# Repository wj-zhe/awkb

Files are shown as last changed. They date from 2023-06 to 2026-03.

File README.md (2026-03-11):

# AWKB - A Weird Keyboard

Nothing fancy, just another Seeed Studio Xiao RP2040 based 36key split keyboard with features like
Japanese Matrix, trackball (pmw3360 based sensor), rotary encoder, and etc.

hardware: https://github.com/wj-zhe/awkb/tree/main/hardware/rev2  
firmware: https://github.com/wj-zhe/awkb/tree/main/firmware/rev2

optical sensor: https://github.com/wj-zhe/optical-sensor

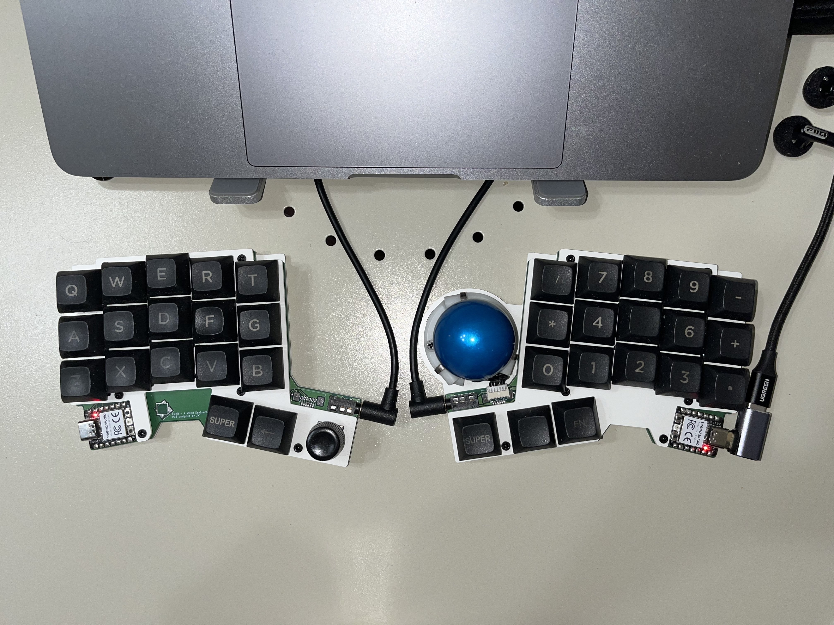
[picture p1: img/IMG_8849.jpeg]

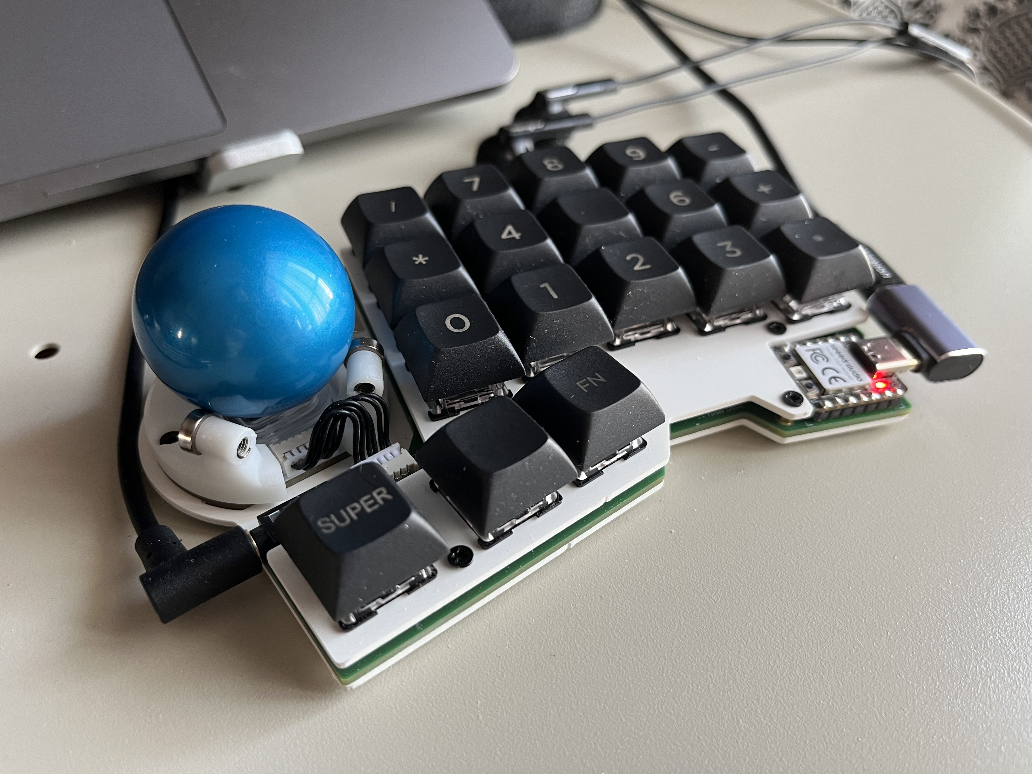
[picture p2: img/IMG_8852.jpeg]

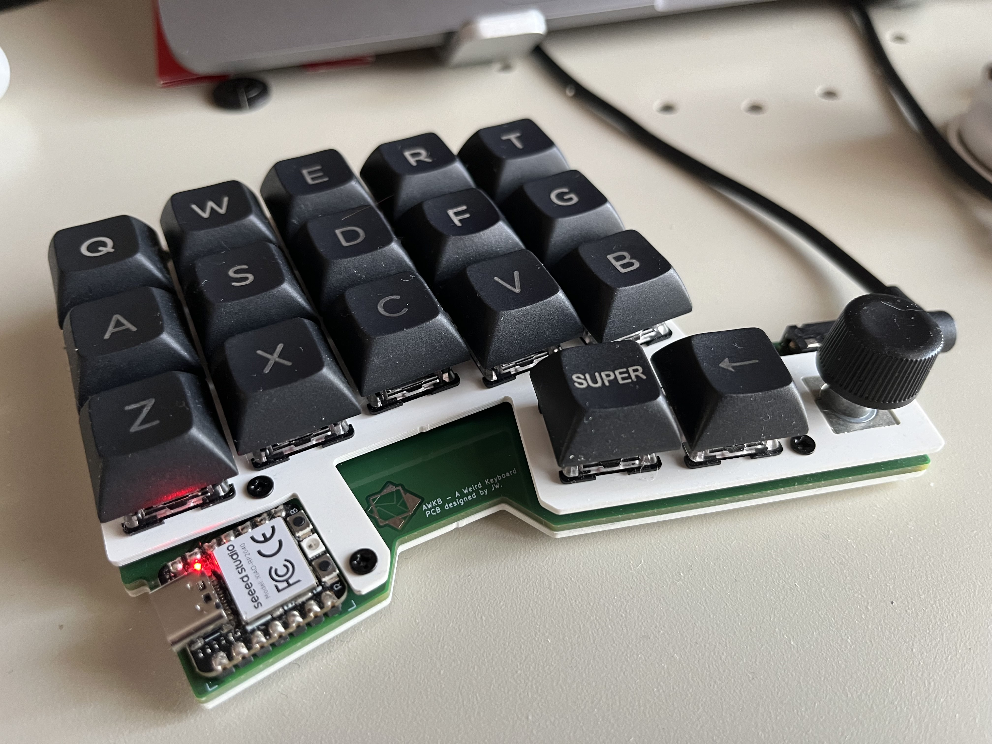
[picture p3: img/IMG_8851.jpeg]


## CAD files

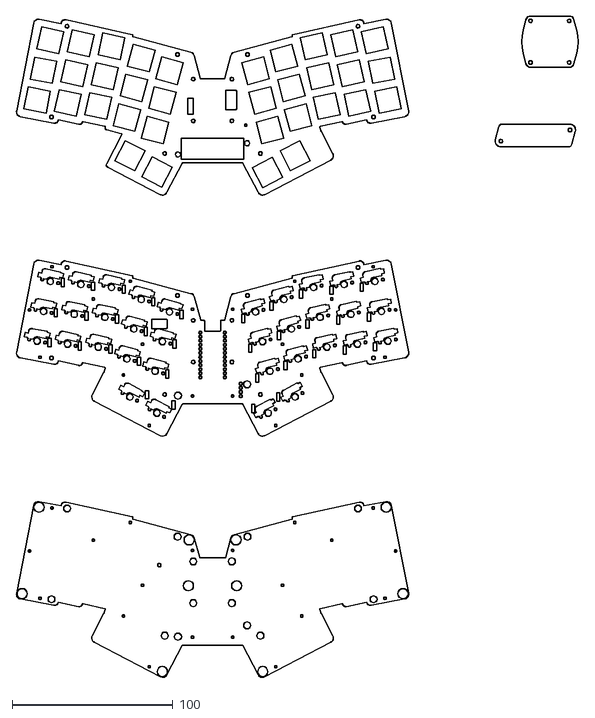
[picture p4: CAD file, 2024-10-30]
hardware/34/monosplit_rev1/case/cirque trackpad 23mm/all-plates-in-one.dxf
349.8 x 411.8

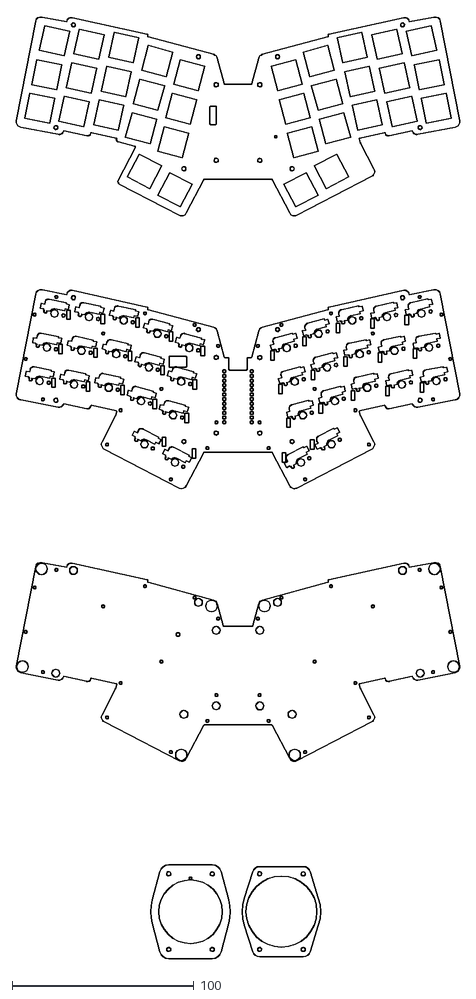
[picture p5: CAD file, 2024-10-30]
hardware/34/monosplit_rev1/case/cirque trackpad 35mm/all-in-one.dxf
244.1 x 518.1

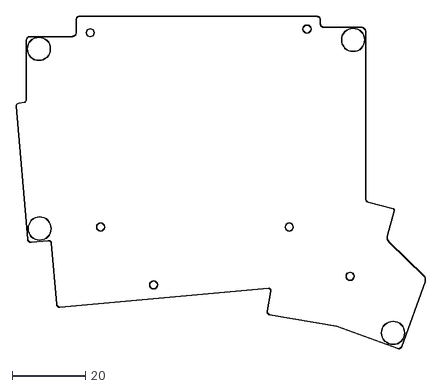
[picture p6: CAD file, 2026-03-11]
hardware/34/rev1/case-acrylic/dxf/AWKB-C-0-bottom-1mm-Edge_Cuts.dxf
111.5 x 90.6

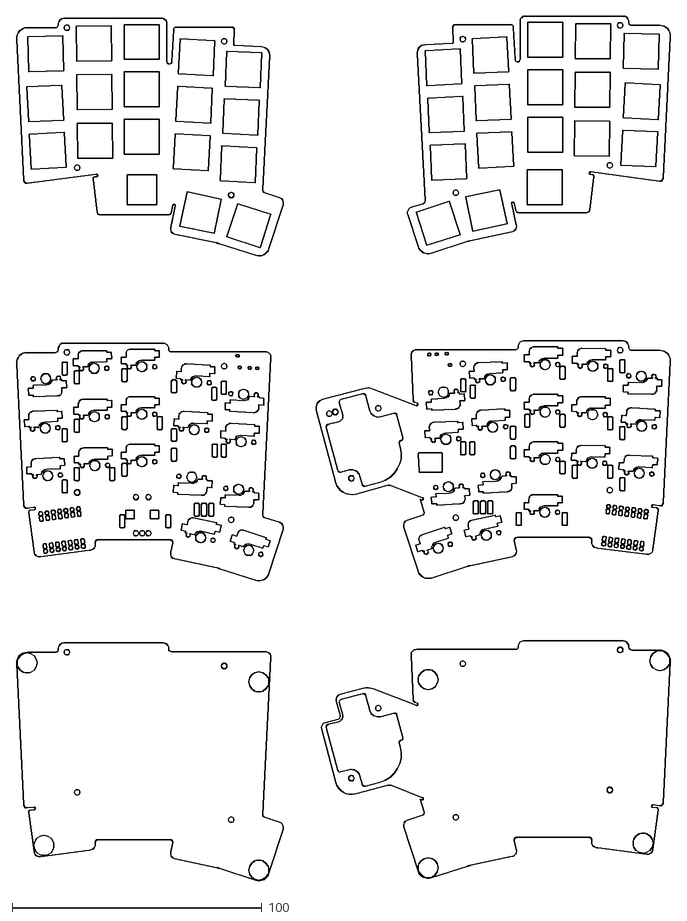
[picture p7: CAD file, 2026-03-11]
hardware/36/rev3/CASE/36_split_v3_stack_case-Edge_Cuts.dxf
261.8 x 346.2

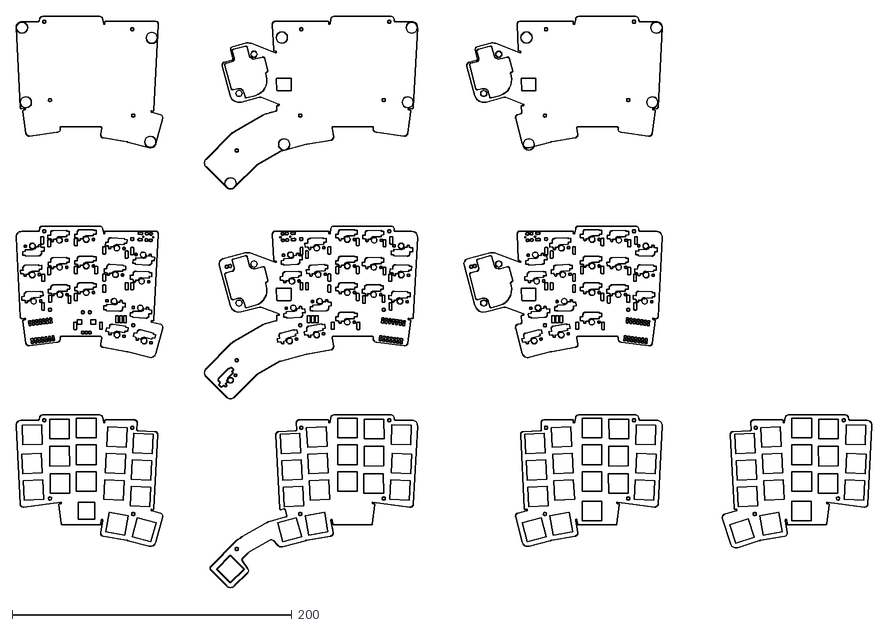
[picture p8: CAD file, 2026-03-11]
hardware/36/rev3/case_temp/gerber/36_split_v3_case-Edge_Cuts.dxf
612.3 x 408.5

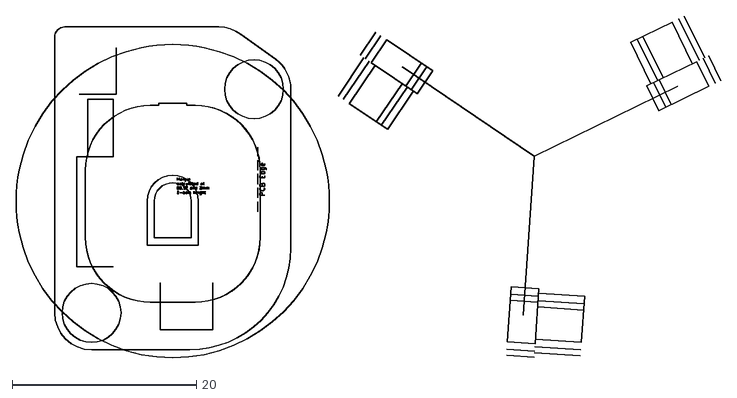
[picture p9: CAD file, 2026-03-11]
hardware/peripherals/pmw3360_fsr/pmw3360_fsr-User_Comments.dxf
76.5 x 37.1

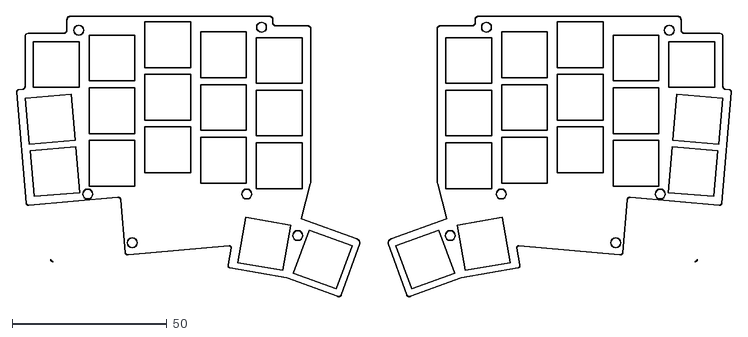
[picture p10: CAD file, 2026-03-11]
hardware/34/rev1/case-acrylic/dxf/AWKB-C-2-above PCB-1mm-Edge_Cuts.dxf
231.0 x 90.6

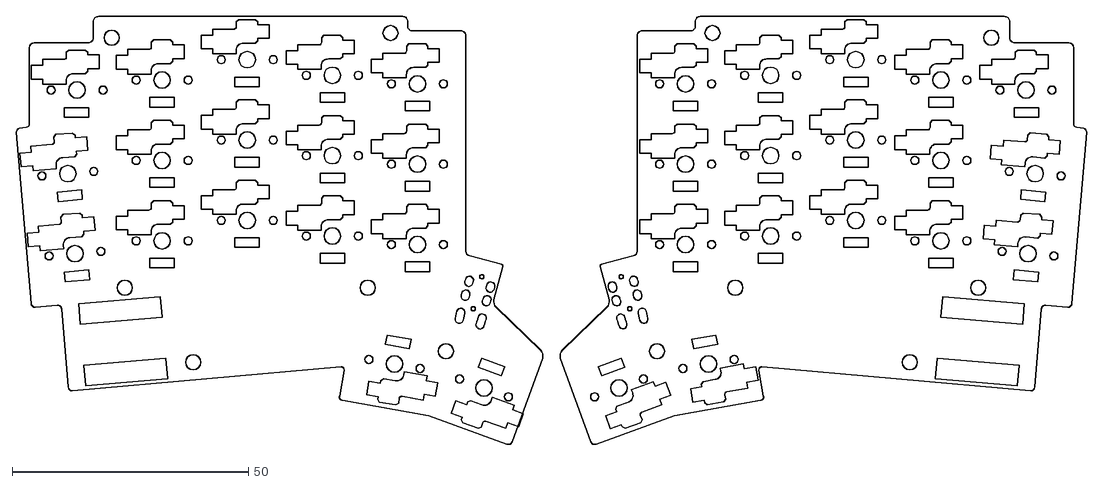
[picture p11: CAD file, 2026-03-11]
hardware/34/rev1/case-acrylic/dxf/AWKB-C-1-under PCB-2mm-Edge_Cuts.dxf
226.5 x 90.6

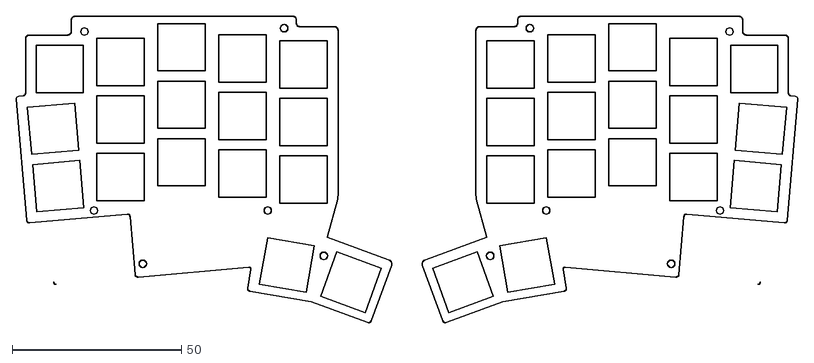
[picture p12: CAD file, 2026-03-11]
hardware/34/rev1/case-acrylic/dxf/AWKB-C-3-switch plate-1mm-Edge_Cuts.dxf
231.0 x 90.6

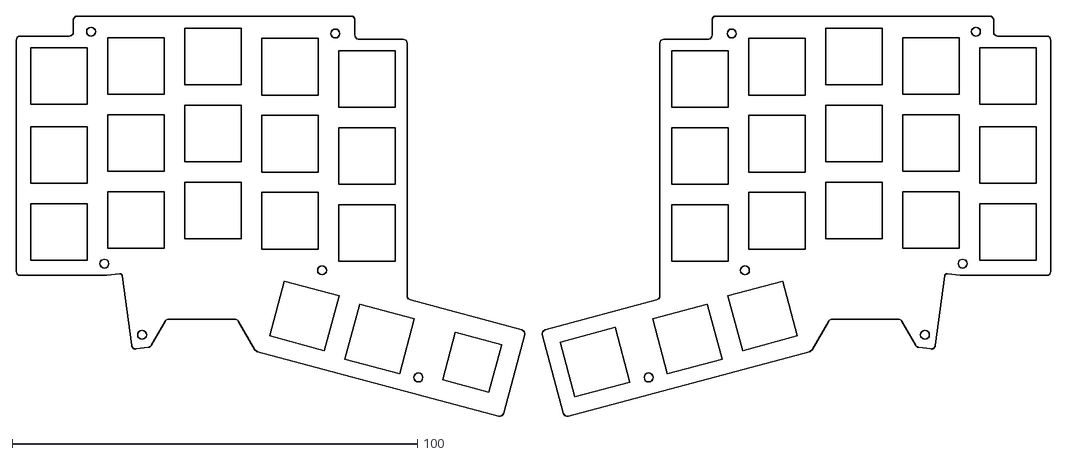
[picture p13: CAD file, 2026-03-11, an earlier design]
hardware/36/rev2/CASE/switch plate/awkb_v2_mx-switch_plate.dxf
255.2 x 98.9

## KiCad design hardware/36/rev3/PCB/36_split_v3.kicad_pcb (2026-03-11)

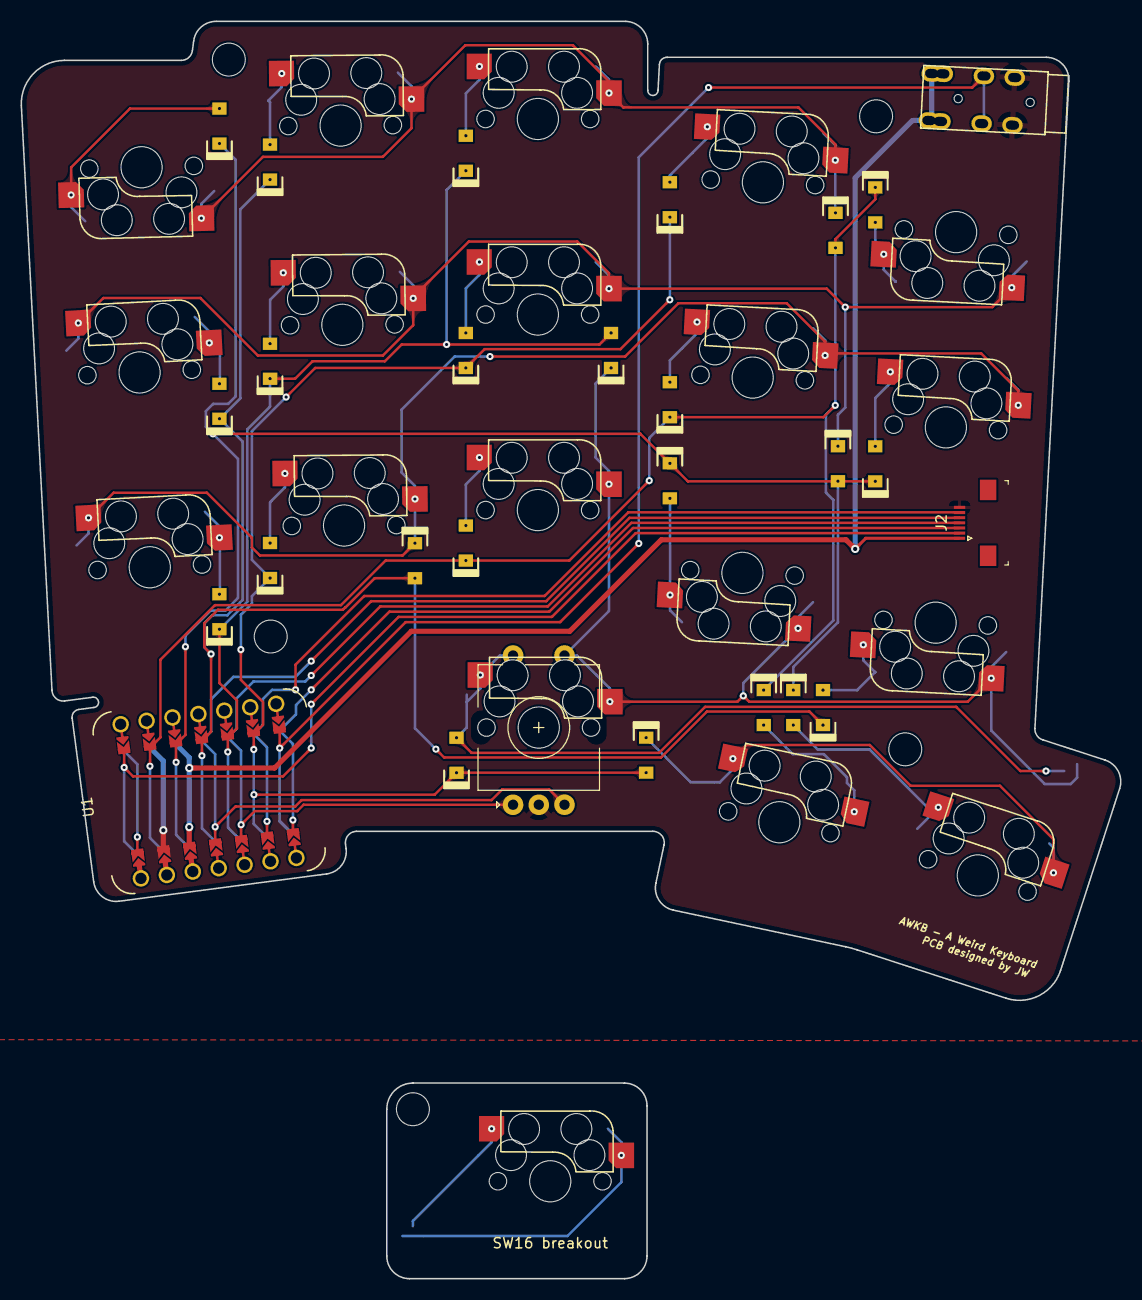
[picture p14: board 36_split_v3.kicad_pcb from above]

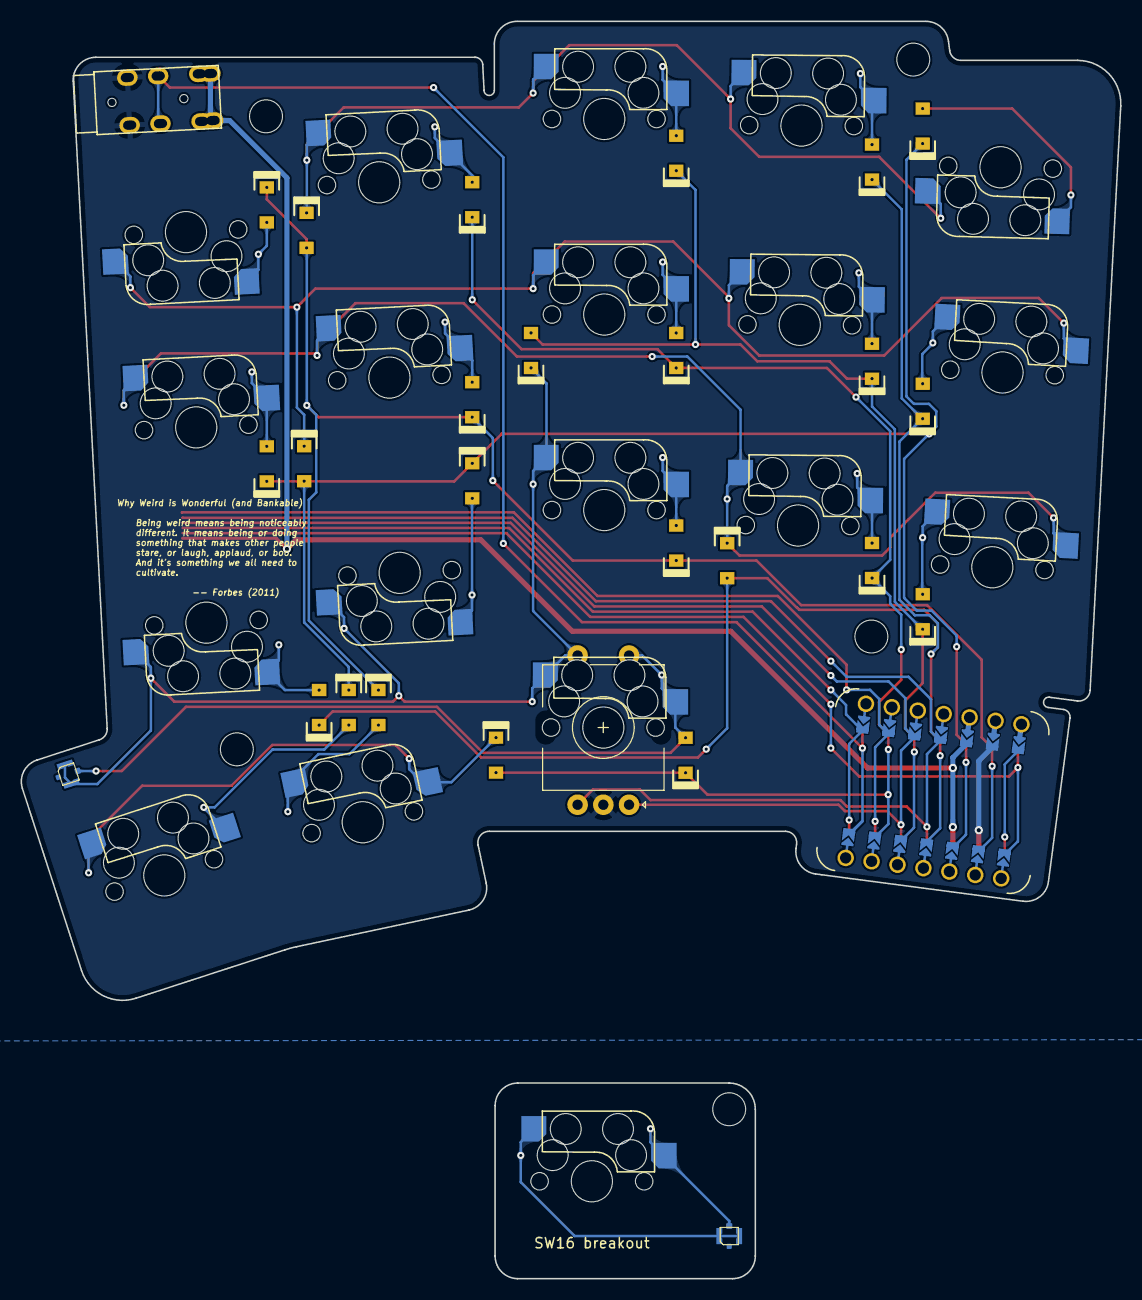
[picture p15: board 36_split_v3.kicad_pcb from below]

Board: 2 copper layers, 106.8 x 95.1 mm, 53 parts (3 on the bottom side), 38 nets.

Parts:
D1, D2, D3, D4, D5, D6, D7, D8, D9, D10, D11, D12, D13, D14, D15, D16, D17, D18: Diode; Diode_SOD123_THT_v3
D-1, D-2, D-3, D-4, D-5: Diode; Diode_SOD123_THT_v3
EC1: Rotary_Encoder_Switch; RotaryEncoder_Alps_EC11E-Switch_Vertical_H20mm_no_copper_MP
J1: 4PIN; TRRS-PJ-DPB2_mod
J2: Conn_01x07_Female; Conn_1x07-1MP_P0.5mm_Horizontal_Flip
J3, J4: Conn_Coaxial; Coaxial_MHF_2D_MHF_4_RECEPTACLE_20449_1C22_IPEX_4
SW1: SW1; CherryMX_Hotswap
SW2: SW2; CherryMX_Hotswap
SW3: SW3; CherryMX_Hotswap
SW4: SW4; CherryMX_Hotswap
SW5: SW5; CherryMX_Hotswap
SW6: SW6; CherryMX_Hotswap
SW7: SW7; CherryMX_Hotswap
SW8: SW8; CherryMX_Hotswap
SW9: SW9; CherryMX_Hotswap
SW10: SW10; CherryMX_Hotswap
SW11: SW11; CherryMX_Hotswap
SW12: SW12; CherryMX_Hotswap
SW13: SW13; CherryMX_Hotswap
SW14: SW14; CherryMX_Hotswap
SW15: SW15; CherryMX_Hotswap
SW16: SW16; CherryMX_Hotswap
SW16-1: SW16-1; CherryMX_Hotswap
SW17: SW17; CherryMX_Hotswap
SW18: SW18; CherryMX_Hotswap
TH1, TH2, TH3, TH4: MountingHole_Pad; MountingHole_3.2mm_M3_ISO14580
THS_1: MountingHole_Pad; MountingHole_3.2mm_M3_ISO14580
U1: SeeeduinoXIAO; Xiao THT jumper pad_flipped

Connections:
3V3: J1.1, J1.4, J2.1, U1.12 (3V3)
DATA: J1.2, U1.7 (PB08_A6_D6_TX)
ES_In: D-4.1 (K), EC1.S1, J3.2 (Ext), SW13.2, SW14.1, SW15.1, SW16.2
ES_Out: D16.2 (A), EC1.S2, J3.1 (In), SW16.1
FSR: J2.2, U1.1 (PA02_A0_D0)
GND: EC1.C, J1.3, J2.7, U1.13 (GND)
MISO_ENCB: EC1.A, J2.4, U1.10 (PA5_A9_D9_MISO)
MOSI_ENCA: EC1.B, J2.5, U1.11 (PA6_A10_D10_MOSI)
NCS: J2.3, U1.8 (PB09_A7_D7_RX)
unnamed: D1.2 (A), SW1.2
unnamed: D2.2 (A), SW2.1
unnamed: D3.2 (A), SW3.1
unnamed: D4.2 (A), SW4.1
unnamed: D5.2 (A), SW5.2
unnamed: D6.2 (A), SW6.2
unnamed: D7.2 (A), SW7.1
unnamed: D8.2 (A), SW8.1
unnamed: D9.2 (A), SW9.1
unnamed: D10.2 (A), SW10.1
unnamed: D11.2 (A), SW11.2
unnamed: D12.2 (A), SW12.1
unnamed: D13.2 (A), SW13.1
unnamed: D14.2 (A), SW14.2
unnamed: D15.2 (A), SW15.2
unnamed: D17.2 (A), SW17.2
unnamed: D18.2 (A), SW18.1
unnamed: D-1.1 (K), SW1.1, SW2.2, SW3.2, SW4.2
unnamed: D-2.1 (K), SW5.1, SW6.1, SW7.2, SW8.2
unnamed: D-3.1 (K), SW9.2, SW10.2, SW11.1, SW12.2
unnamed: D-5.1 (K), SW17.1, SW18.2
unnamed: J4.2 (Ext), SW16-1.2
unnamed: J4.1 (In), SW16-1.1
SCLK: J2.6, U1.9 (PA7_A8_D8_SCK)
pin0: D5.1 (K), D9.1 (K), D13.1 (K), D17.1 (K), D-1.2 (A), U1.2 (PA4_A1_D1)
pin1: D1.1 (K), D10.1 (K), D14.1 (K), D18.1 (K), D-2.2 (A), U1.3 (PA10_A2_D2)
pin2: D2.1 (K), D6.1 (K), D15.1 (K), D-3.2 (A), U1.4 (PA11_A3_D3)
pin3: D3.1 (K), D7.1 (K), D11.1 (K), D-4.2 (A), U1.5 (PA8_A4_D4_SDA)
pin4: D4.1 (K), D8.1 (K), D12.1 (K), D16.1 (K), D-5.2 (A), U1.6 (PA9_A5_D5_SCL)

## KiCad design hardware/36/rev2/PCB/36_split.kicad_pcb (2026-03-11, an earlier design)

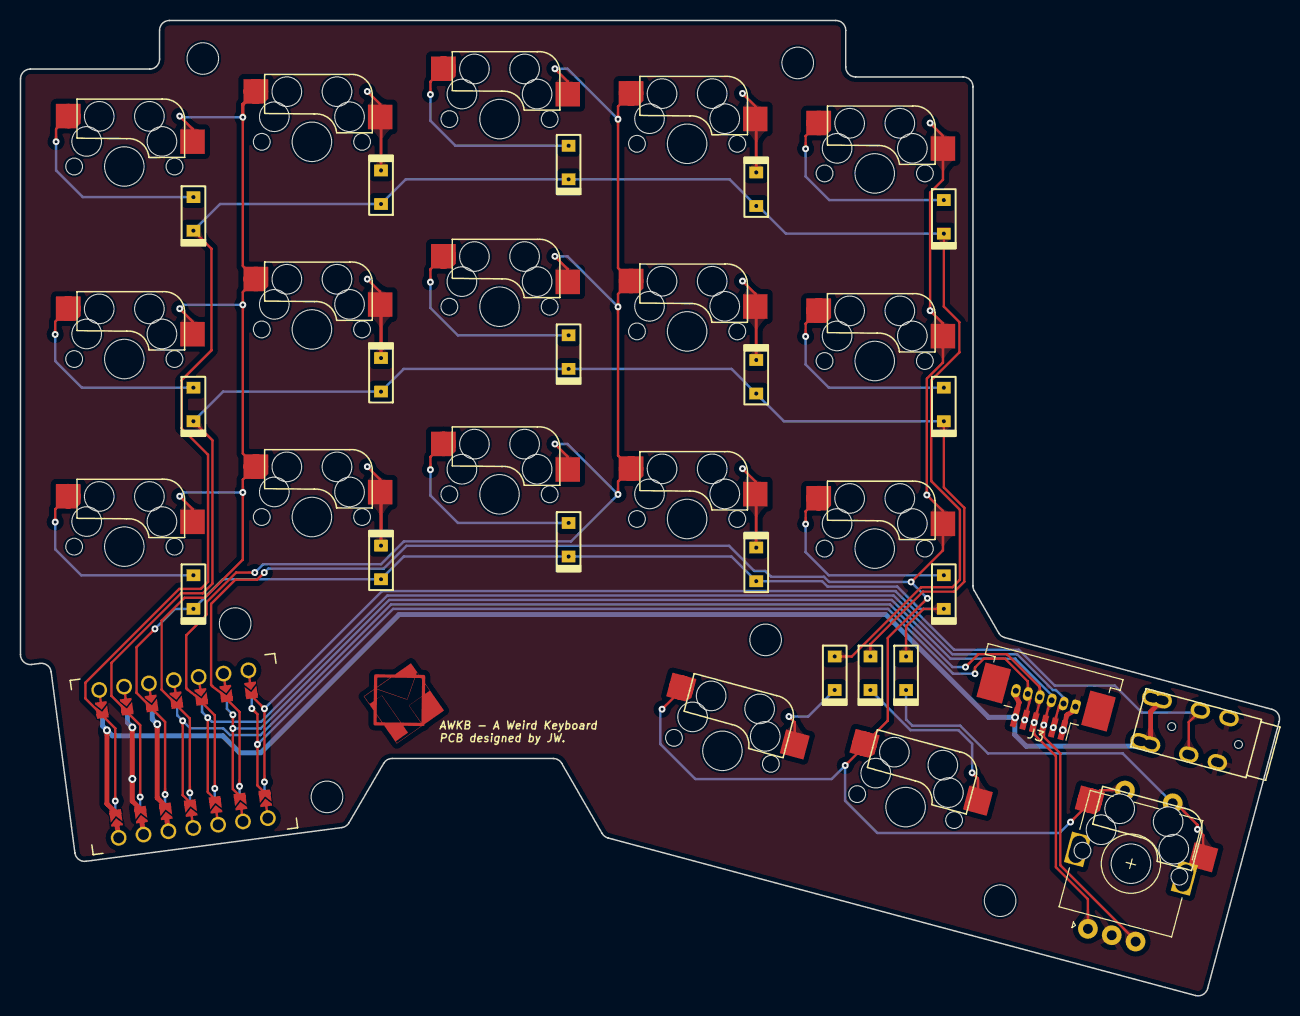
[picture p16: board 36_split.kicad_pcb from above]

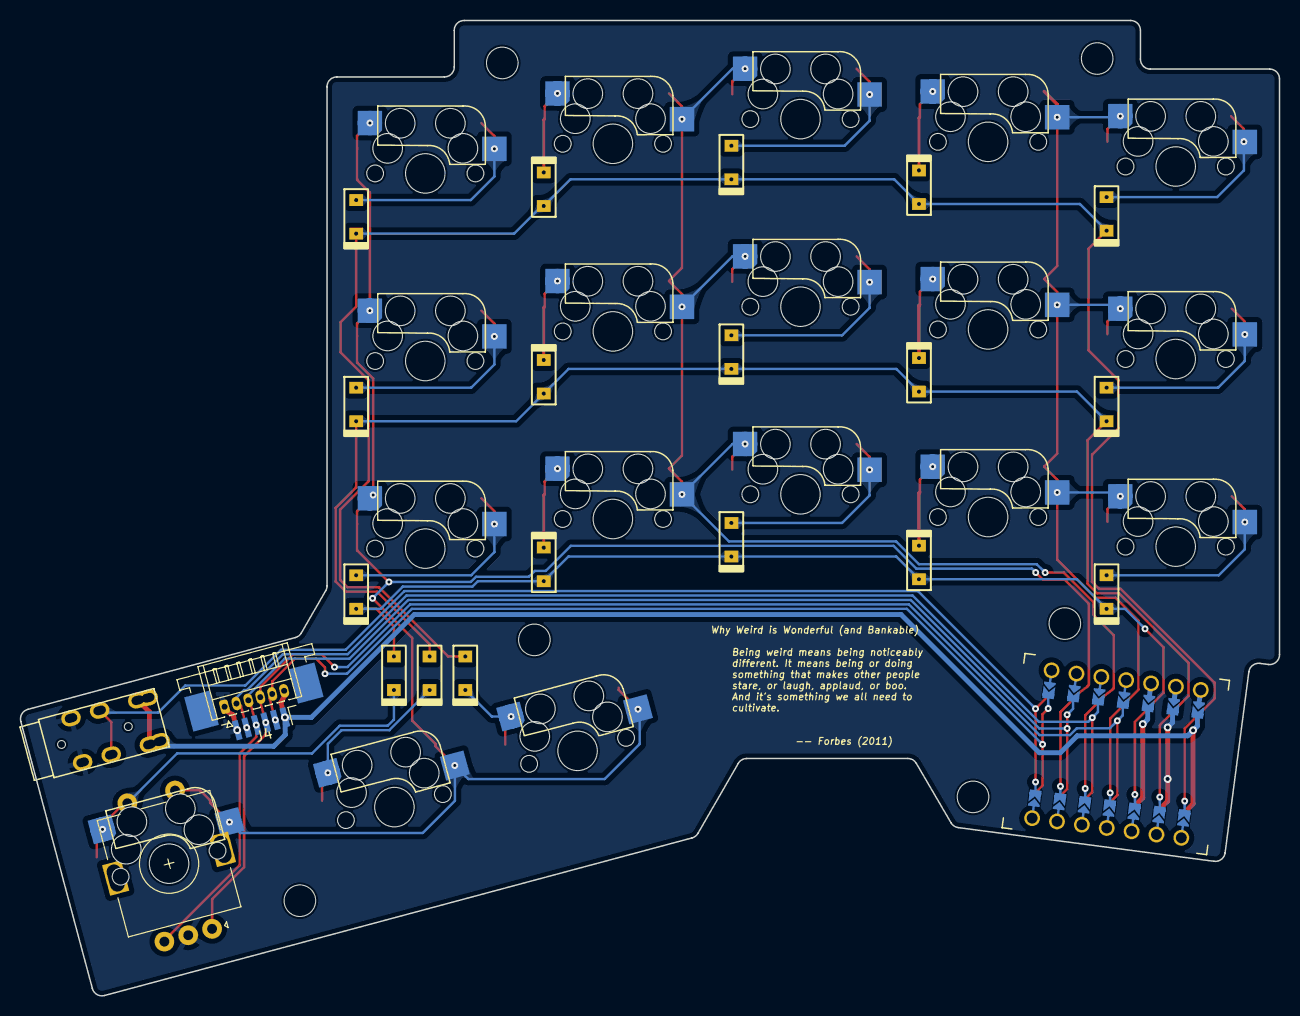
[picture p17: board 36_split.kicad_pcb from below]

Board: 2 copper layers, 127.5 x 98.8 mm, 48 parts (3 on the bottom side), 31 nets.

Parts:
D1, D2, D3, D4, D5, D6, D7, D8, D9, D10, D11, D12, D13, D14, D15, D16, D17, D18: Diode; Diode_SOD123_THT_2
EC1: Rotary_Encoder_Switch; RotaryEncoder_Alps_EC11E-Switch_Vertical_H20mm
J1: 4PIN; TRRS-PJ-DPB2_mod
J2: Conn_01x06_Female; Hirose_DF13-06P-1.25DS_1x06_P1.25mm_Horizontal
J3, J4: Conn_01x06_Female; TE_84952-6_1x06-1MP_P1.0mm_Horizontal
SW1: SW1; CherryMX_Hotswap
SW2: SW2; CherryMX_Hotswap
SW3: SW3; CherryMX_Hotswap
SW4: SW4; CherryMX_Hotswap
SW5: SW5; CherryMX_Hotswap
SW6: SW6; CherryMX_Hotswap
SW7: SW7; CherryMX_Hotswap
SW8: SW8; CherryMX_Hotswap
SW9: SW9; CherryMX_Hotswap
SW10: SW10; CherryMX_Hotswap
SW11: SW11; CherryMX_Hotswap
SW12: SW12; CherryMX_Hotswap
SW13: SW13; CherryMX_Hotswap
SW14: SW14; CherryMX_Hotswap
SW15: SW15; CherryMX_Hotswap
SW16: SW16; CherryMX_Hotswap
SW17: SW17; CherryMX_Hotswap
SW18: SW18; CherryMX_Hotswap
TH1, TH2, TH3, TH4, TH5, TH6: HOLE; MountingHole_3.2mm_M3
U1: SeeeduinoXIAO; Xiao THT jumper pad_flipped

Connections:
DATA: J1.2, U1.7 (PB08_A6_D6_TX)
GND: EC1.C, J1.3, J2.1, J3.1, J4.6, U1.13 (GND)
MISO: J2.2, J3.2, J4.5, U1.10 (PA5_A9_D9_MISO)
MOSI_ENCA: EC1.A, J2.4, J3.4, J4.3, U1.11 (PA6_A10_D10_MOSI)
NCS: J2.5, J3.5, J4.2, U1.8 (PB09_A7_D7_RX)
unnamed: D1.2 (A), SW1.1
unnamed: D2.1 (K), SW2.2
unnamed: D3.2 (A), SW3.1
unnamed: D4.1 (K), SW4.2
unnamed: D5.2 (A), SW5.1
unnamed: D6.2 (A), SW6.1
unnamed: D7.1 (K), SW7.2
unnamed: D8.2 (A), SW8.1
unnamed: D9.1 (K), SW9.2
unnamed: D10.2 (A), SW10.1
unnamed: D11.2 (A), SW11.1
unnamed: D12.1 (K), SW12.2
unnamed: D13.2 (A), SW13.1
unnamed: D14.1 (K), SW14.2
unnamed: D15.2 (A), SW15.1
unnamed: D16.1 (K), SW16.2
unnamed: D17.1 (K), SW17.2
SCLK_ENCB: EC1.B, J2.3, J3.3, J4.4, U1.9 (PA7_A8_D8_SCK)
VDD_5V: J1.1, J1.4, J2.6, J3.6, J4.1, U1.14 (5V)
col0: SW1.2, SW2.1, SW6.2, SW7.1, SW11.2, SW12.1, U1.4 (PA11_A3_D3)
col1: SW3.2, SW4.1, SW8.2, SW9.1, SW13.2, SW14.1, U1.5 (PA8_A4_D4_SDA)
col2: EC1.S2, SW5.2, SW10.2, SW15.2, SW16.1, SW17.1, SW18.1, U1.6 (PA9_A5_D5_SCL)
row0: D1.1 (K), D2.2 (A), D3.1 (K), D4.2 (A), D5.1 (K), D16.2 (A), U1.1 (PA02_A0_D0)
row1: D6.1 (K), D7.2 (A), D8.1 (K), D9.2 (A), D10.1 (K), D17.2 (A), U1.2 (PA4_A1_D1)
row2: D11.1 (K), D12.2 (A), D13.1 (K), D14.2 (A), D15.1 (K), D18.2 (A), U1.3 (PA10_A2_D2)
sw_row: D18.1 (K), EC1.S1, SW18.2

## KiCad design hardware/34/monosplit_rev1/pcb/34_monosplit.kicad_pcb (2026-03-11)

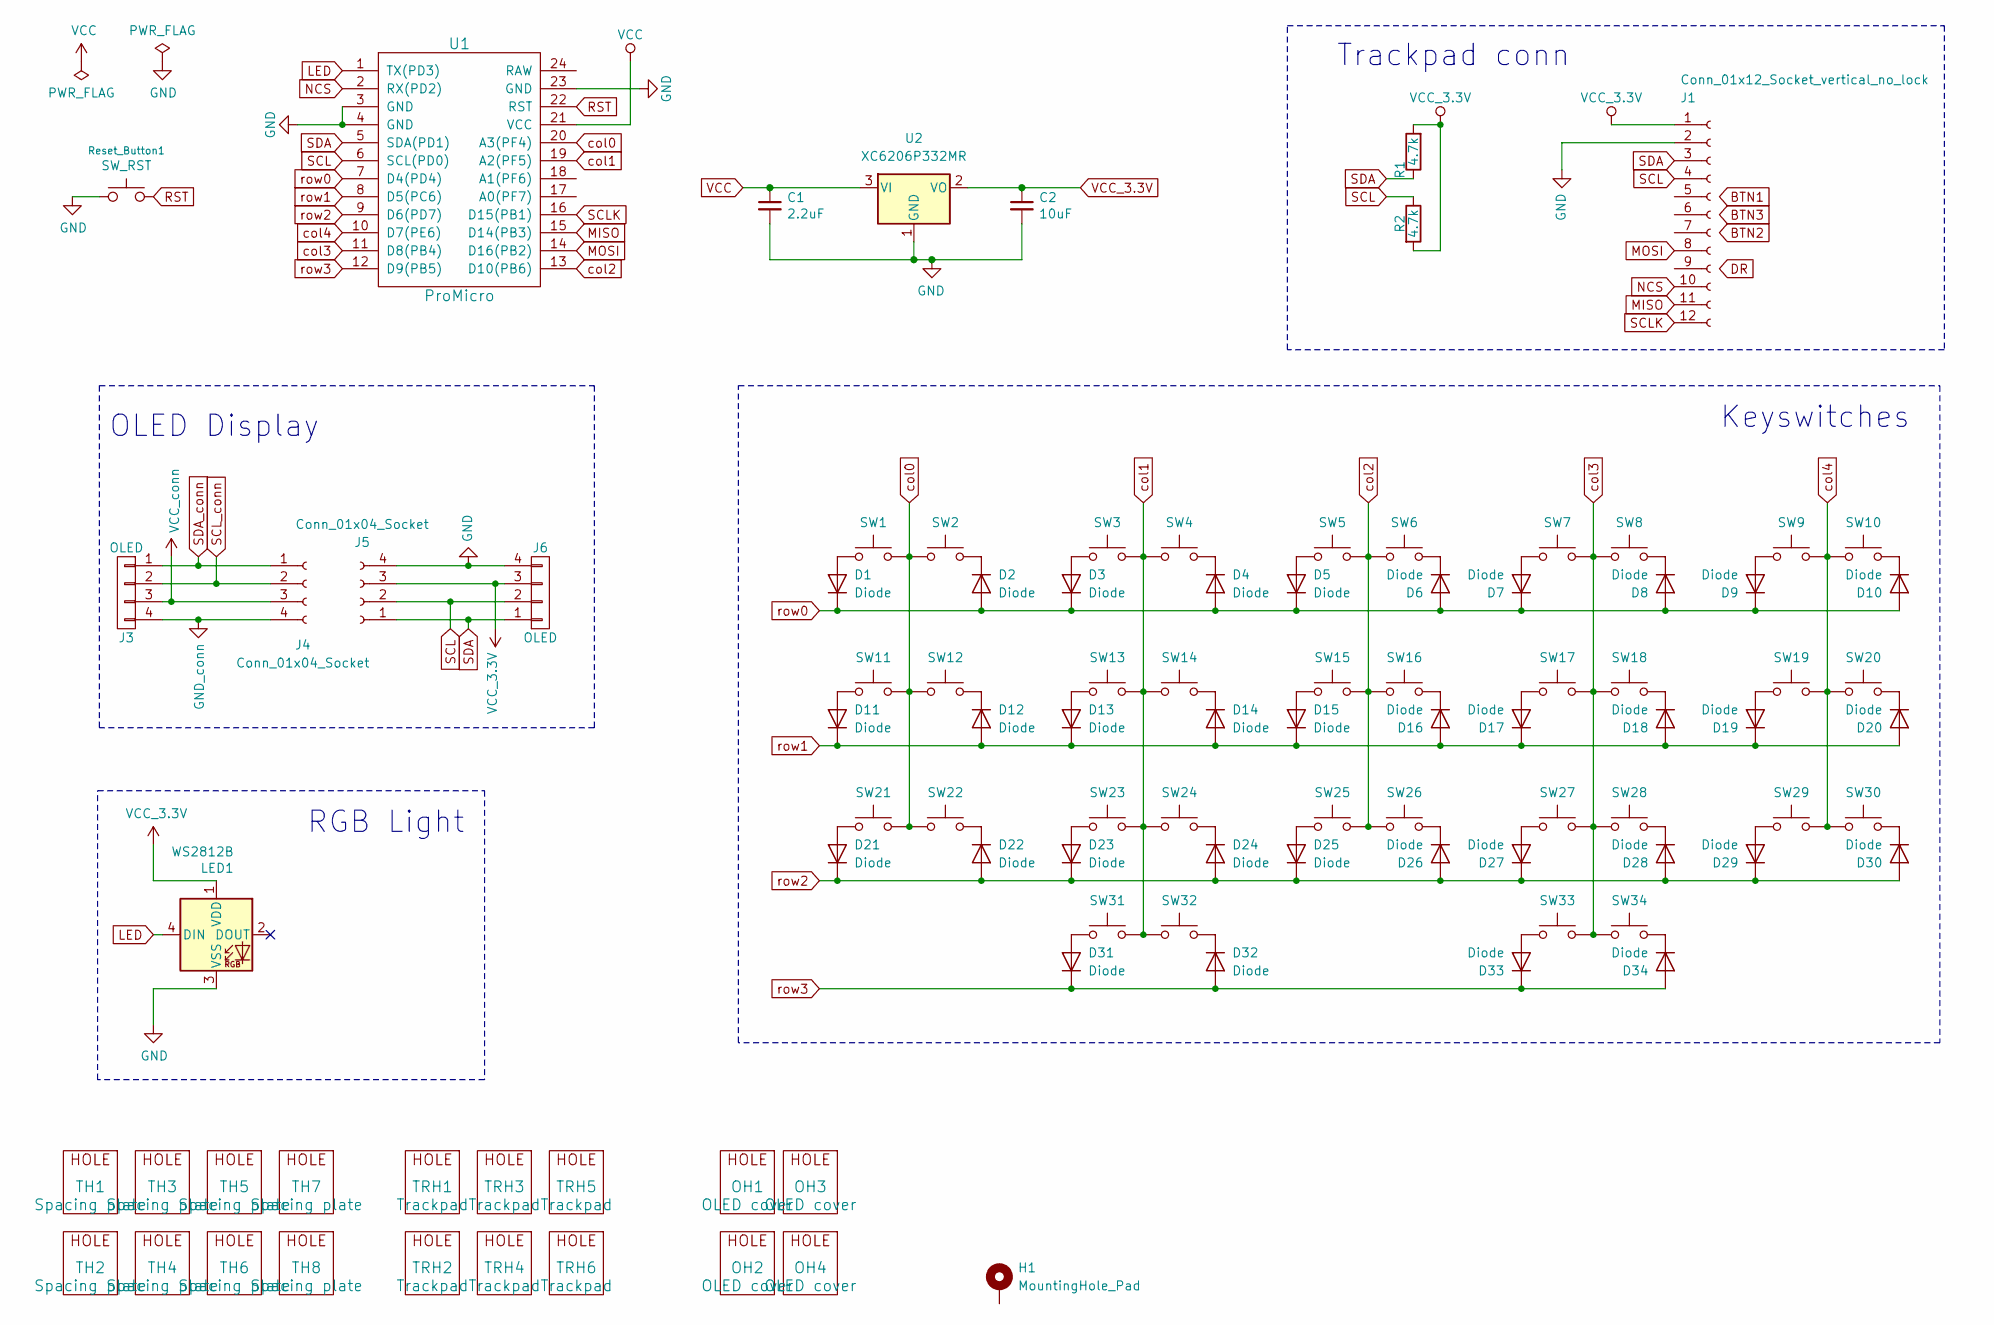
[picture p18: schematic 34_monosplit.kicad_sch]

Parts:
C1: 2.2uF; D_1206_3216Metric_Pad1.42x1.75mm_HandSolder; LCSC C1858
C2: 10uF; D_1206_3216Metric_Pad1.42x1.75mm_HandSolder; LCSC C152957
D1, D2, D3, D4, D5, D6, D7, D8, D9, D10, D11, D12, D13, D14, D15, D16, D17, D18, D19, D20, D21, D22, D23, D24, D25, D26, D27, D28, D29, D30, D31, D32, D33, D34: Diode; Diode_SOD123_SMD
H1: MountingHole_Pad; square_1
J1: Conn_01x12_Socket_vertical_no_lock; Hirose_FH12-12S-0.5SH_1x12-1MP_P0.50mm_Vertical_custom
J3, J6: OLED; PinSocket_1x04_P2.54mm_Vertical
J4, J5: Conn_01x04_Socket; Molex_200528-0040_1x04-1MP_P1.00mm_Horizontal
LED1: WS2812B; LED_WS2812B_PLCC4_5.0x5.0mm_P3.2mm
OH1, OH2, OH3, OH4: OLED cover; MountingHole_2.2mm_M2_ISO7380_Pad
R1, R2: 4.7k; R_1206_3216Metric_Pad1.30x1.75mm_HandSolder; LCSC C269746
Reset_Button1: SW_RST; SW_SPST_TL3342
SW1: SW1; CherryMX_Hotswap_single_side
SW2: SW2; CherryMX_Hotswap_single_side
SW3: SW3; CherryMX_Hotswap_single_side
SW4: SW4; CherryMX_Hotswap_single_side
SW5: SW5; CherryMX_Hotswap_single_side
SW6: SW6; CherryMX_Hotswap_single_side
SW7: SW7; CherryMX_Hotswap_single_side
SW8: SW8; CherryMX_Hotswap_single_side
SW9: SW9; CherryMX_Hotswap_single_side
SW10: SW10; CherryMX_Hotswap_single_side
SW11: SW11; CherryMX_Hotswap_single_side
SW12: SW12; CherryMX_Hotswap_single_side
SW13: SW13; CherryMX_Hotswap_single_side
SW14: SW14; CherryMX_Hotswap_single_side
SW15: SW15; CherryMX_Hotswap_single_side
SW16: SW16; CherryMX_Hotswap_single_side
SW17: SW17; CherryMX_Hotswap_single_side
SW18: SW18; CherryMX_Hotswap_single_side
SW19: SW19; CherryMX_Hotswap_single_side
SW20: SW20; CherryMX_Hotswap_single_side
SW21: SW21; CherryMX_Hotswap_single_side
SW22: SW22; CherryMX_Hotswap_single_side
SW23: SW23; CherryMX_Hotswap_single_side
SW24: SW24; CherryMX_Hotswap_single_side
SW25: SW25; CherryMX_Hotswap_single_side
SW26: SW26; CherryMX_Hotswap_single_side
SW27: SW27; CherryMX_Hotswap_single_side
SW28: SW28; CherryMX_Hotswap_single_side
SW29: SW29; CherryMX_Hotswap_single_side
SW30: SW30; CherryMX_Hotswap_single_side
SW31: SW31; CherryMX_Hotswap_single_side
SW32: SW32; CherryMX_Hotswap_single_side
SW33: SW33; CherryMX_Hotswap_single_side
SW34: SW34; CherryMX_Hotswap_single_side
TH1, TH2, TH3, TH4, TH5, TH6, TH7, TH8: Spacing plate; MountingHole_3.2mm_M3
TRH1, TRH2, TRH3, TRH4, TRH5, TRH6: Trackpad; MountingHole_3.2mm_M3
U1: ProMicro; ProMicro_1.1mm_hole_only
U2: XC6206P332MR; TSOT-23_HandSoldering; LCSC C347376

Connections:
GND: C1.2, C2.2, J1.2, J5.4, J6.4, LED1.3 (VSS), Reset_Button1.1, U1.3 (GND), U1.4 (GND), U1.23 (GND), U2.1 (GND)
GND_conn: J3.4, J4.4
LED: LED1.4 (DIN), U1.1 (TX(PD3))
MISO: J1.11, U1.15 (D14(PB3))
MOSI: J1.8, U1.14 (D16(PB2))
NCS: J1.10, U1.2 (RX(PD2))
unnamed: D1.2 (A), SW1.1
unnamed: D2.1 (K), SW2.2
unnamed: D3.2 (A), SW3.1
unnamed: D4.1 (K), SW4.2
unnamed: D5.2 (A), SW5.1
unnamed: D6.1 (K), SW6.2
unnamed: D7.2 (A), SW7.1
unnamed: D8.1 (K), SW8.2
unnamed: D9.2 (A), SW9.1
unnamed: D10.1 (K), SW10.2
unnamed: D11.2 (A), SW11.1
unnamed: D12.1 (K), SW12.2
unnamed: D13.2 (A), SW13.1
unnamed: D14.1 (K), SW14.2
unnamed: D15.2 (A), SW15.1
unnamed: D16.1 (K), SW16.2
unnamed: D17.2 (A), SW17.1
unnamed: D18.1 (K), SW18.2
unnamed: D19.2 (A), SW19.1
unnamed: D20.1 (K), SW20.2
unnamed: D21.2 (A), SW21.1
unnamed: D22.1 (K), SW22.2
unnamed: D23.2 (A), SW23.1
unnamed: D24.1 (K), SW24.2
unnamed: D25.2 (A), SW25.1
unnamed: D26.1 (K), SW26.2
unnamed: D27.2 (A), SW27.1
unnamed: D28.1 (K), SW28.2
unnamed: D29.2 (A), SW29.1
unnamed: D30.1 (K), SW30.2
unnamed: D31.2 (A), SW31.1
unnamed: D32.1 (K), SW32.2
unnamed: D33.2 (A), SW33.1
unnamed: D34.1 (K), SW34.2
RST: Reset_Button1.2, U1.22 (RST)
SCL: J1.4, J5.2, J6.2, R2.1, U1.6 (SCL(PD0))
SCLK: J1.12, U1.16 (D15(PB1))
SCL_conn: J3.2, J4.2
SDA: J1.3, J5.1, J6.1, R1.1, U1.5 (SDA(PD1))
SDA_conn: J3.1, J4.1
VCC: C1.1, U1.21 (VCC), U2.3 (VI)
VCC_3.3V: C2.1, J1.1, J5.3, J6.3, LED1.1 (VDD), R1.2, R2.2, U2.2 (VO)
VCC_conn: J3.3, J4.3
col0: SW1.2, SW2.1, SW11.2, SW12.1, SW21.2, SW22.1, U1.20 (A3(PF4))
col1: SW3.2, SW4.1, SW13.2, SW14.1, SW23.2, SW24.1, SW31.2, SW32.1, U1.19 (A2(PF5))
col2: SW5.2, SW6.1, SW15.2, SW16.1, SW25.2, SW26.1, U1.13 (D10(PB6))
col3: SW7.2, SW8.1, SW17.2, SW18.1, SW27.2, SW28.1, SW33.2, SW34.1, U1.11 (D8(PB4))
col4: SW9.2, SW10.1, SW19.2, SW20.1, SW29.2, SW30.1, U1.10 (D7(PE6))
row0: D1.1 (K), D2.2 (A), D3.1 (K), D4.2 (A), D5.1 (K), D6.2 (A), D7.1 (K), D8.2 (A), D9.1 (K), D10.2 (A), U1.7 (D4(PD4))
row1: D11.1 (K), D12.2 (A), D13.1 (K), D14.2 (A), D15.1 (K), D16.2 (A), D17.1 (K), D18.2 (A), D19.1 (K), D20.2 (A), U1.8 (D5(PC6))
row2: D21.1 (K), D22.2 (A), D23.1 (K), D24.2 (A), D25.1 (K), D26.2 (A), D27.1 (K), D28.2 (A), D29.1 (K), D30.2 (A), U1.9 (D6(PD7))
row3: D31.1 (K), D32.2 (A), D33.1 (K), D34.2 (A), U1.12 (D9(PB5))

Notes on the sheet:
RGB Light
Trackpad conn
OLED Display
Keyswitches

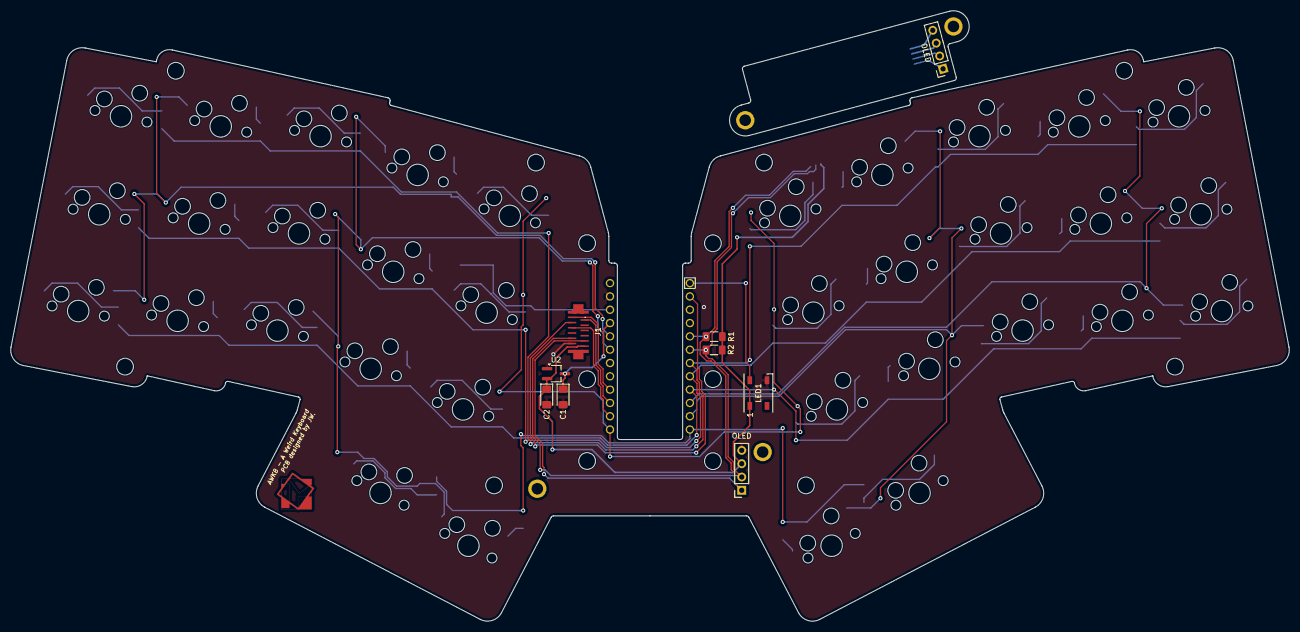
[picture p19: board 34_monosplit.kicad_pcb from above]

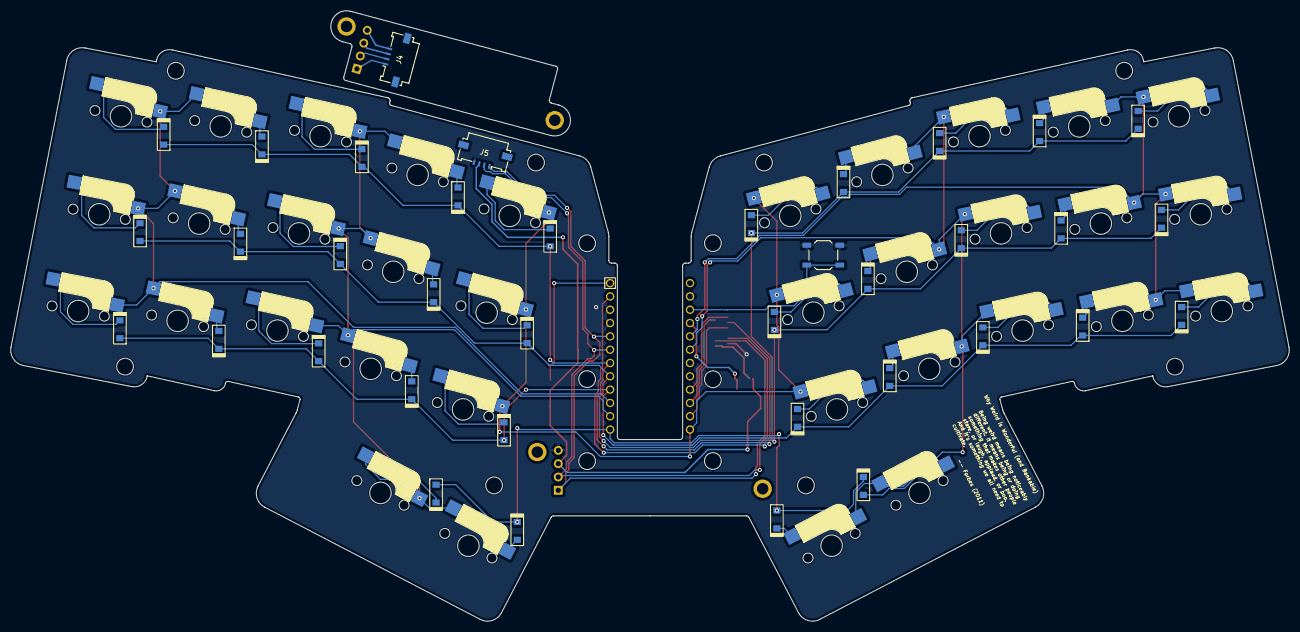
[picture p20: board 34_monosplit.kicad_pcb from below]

Board: 2 copper layers, 243.9 x 116.5 mm, 100 parts (38 on the bottom side), 58 nets.

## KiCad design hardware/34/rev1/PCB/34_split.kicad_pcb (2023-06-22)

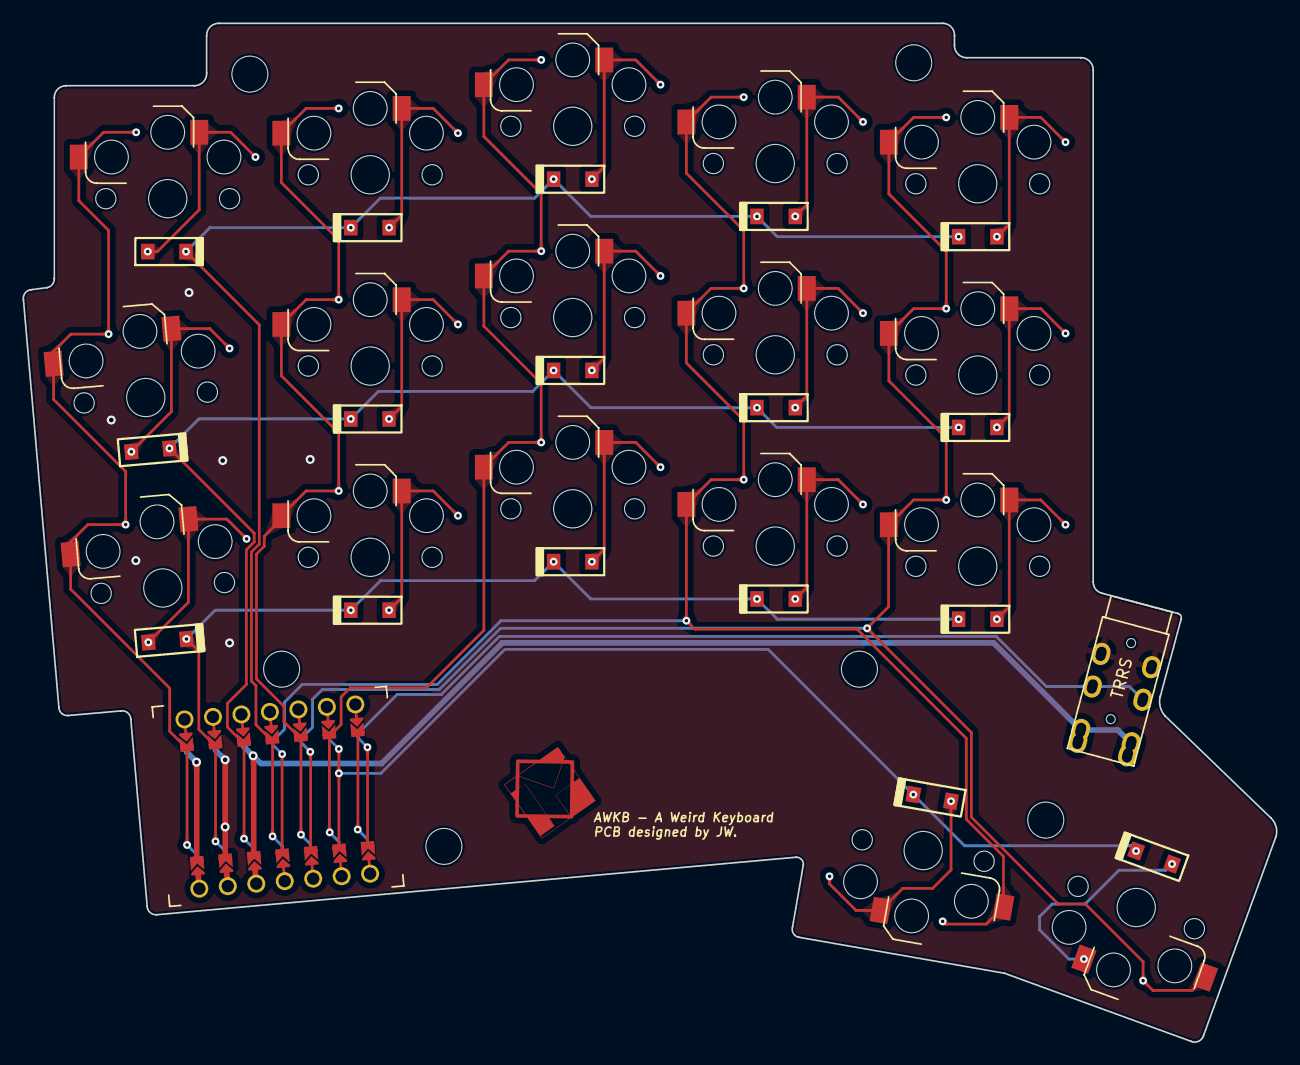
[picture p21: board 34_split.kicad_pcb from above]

Board: 2 copper layers, 111.4 x 90.5 mm, 42 parts (0 on the bottom side), 29 nets.

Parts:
D1, D2, D3, D4, D5, D6, D7, D8, D9, D10, D11, D12, D13, D14, D15, D16, D17: D; Diode_SOD123_wo_THT
J1: 4PIN; TRRS-PJ-DPB2_mod
SW1: SW1; Kailh_Choc_PG1350_Hotswap_reversible
SW2: SW2; Kailh_Choc_PG1350_Hotswap_reversible
SW3: SW3; Kailh_Choc_PG1350_Hotswap_reversible
SW4: SW4; Kailh_Choc_PG1350_Hotswap_reversible
SW5: SW5; Kailh_Choc_PG1350_Hotswap_reversible
SW6: SW6; Kailh_Choc_PG1350_Hotswap_reversible
SW7: SW7; Kailh_Choc_PG1350_Hotswap_reversible
SW8: SW8; Kailh_Choc_PG1350_Hotswap_reversible
SW9: SW9; Kailh_Choc_PG1350_Hotswap_reversible
SW10: SW10; Kailh_Choc_PG1350_Hotswap_reversible
SW11: SW11; Kailh_Choc_PG1350_Hotswap_reversible
SW12: SW12; Kailh_Choc_PG1350_Hotswap_reversible
SW13: SW13; Kailh_Choc_PG1350_Hotswap_reversible
SW14: SW14; Kailh_Choc_PG1350_Hotswap_reversible
SW15: SW15; Kailh_Choc_PG1350_Hotswap_reversible
SW16: SW16; Kailh_Choc_PG1350_Hotswap_reversible
SW17: SW17; Kailh_Choc_PG1350_Hotswap_reversible
TH1, TH2, TH3, TH4, TH5, TH6: HOLE; MountingHole_3.2mm_M3
U1: SeeeduinoXIAO; Xiao THT jumper pad_flipped

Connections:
DATA: J1.2, U1.8 (PB09_A7_D7_RX)
GND: J1.3, U1.13 (GND)
unnamed: D1.2 (A), SW1.2
unnamed: D2.2 (A), SW2.2
unnamed: D3.2 (A), SW3.2
unnamed: D4.2 (A), SW4.2
unnamed: D5.2 (A), SW5.2
unnamed: D6.2 (A), SW6.2
unnamed: D7.2 (A), SW7.2
unnamed: D8.2 (A), SW8.2
unnamed: D9.2 (A), SW9.2
unnamed: D10.2 (A), SW10.2
unnamed: D11.2 (A), SW11.2
unnamed: D12.2 (A), SW12.2
unnamed: D13.2 (A), SW13.2
unnamed: D14.2 (A), SW14.2
unnamed: D15.2 (A), SW15.2
unnamed: D16.2 (A), SW16.2
unnamed: D17.2 (A), SW17.2
VCC: J1.1, J1.4, U1.12 (3V3)
col0: SW1.1, SW6.1, SW11.1, U1.1 (PA02_A0_D0)
col1: SW2.1, SW7.1, SW12.1, U1.5 (PA8_A4_D4_SDA)
col2: SW3.1, SW8.1, SW13.1, U1.6 (PA9_A5_D5_SCL)
col3: SW4.1, SW9.1, SW14.1, SW16.1, U1.11 (PA6_A10_D10_MOSI)
col4: SW5.1, SW10.1, SW15.1, SW17.1, U1.10 (PA5_A9_D9_MISO)
row0: D1.1 (K), D2.1 (K), D3.1 (K), D4.1 (K), D5.1 (K), U1.4 (PA11_A3_D3)
row1: D6.1 (K), D7.1 (K), D8.1 (K), D9.1 (K), D10.1 (K), U1.3 (PA10_A2_D2)
row2: D11.1 (K), D12.1 (K), D13.1 (K), D14.1 (K), D15.1 (K), U1.2 (PA4_A1_D1)
row3: D16.1 (K), D17.1 (K), U1.9 (PA7_A8_D8_SCK)

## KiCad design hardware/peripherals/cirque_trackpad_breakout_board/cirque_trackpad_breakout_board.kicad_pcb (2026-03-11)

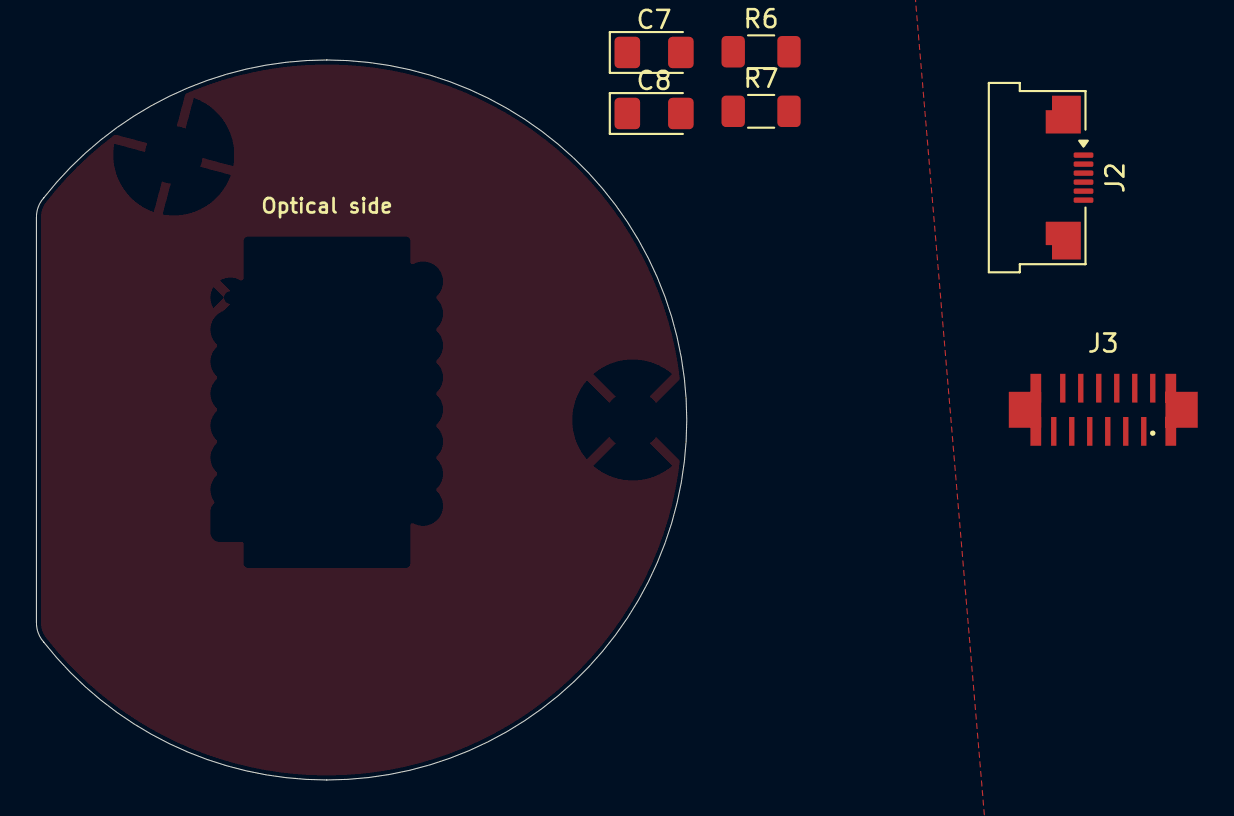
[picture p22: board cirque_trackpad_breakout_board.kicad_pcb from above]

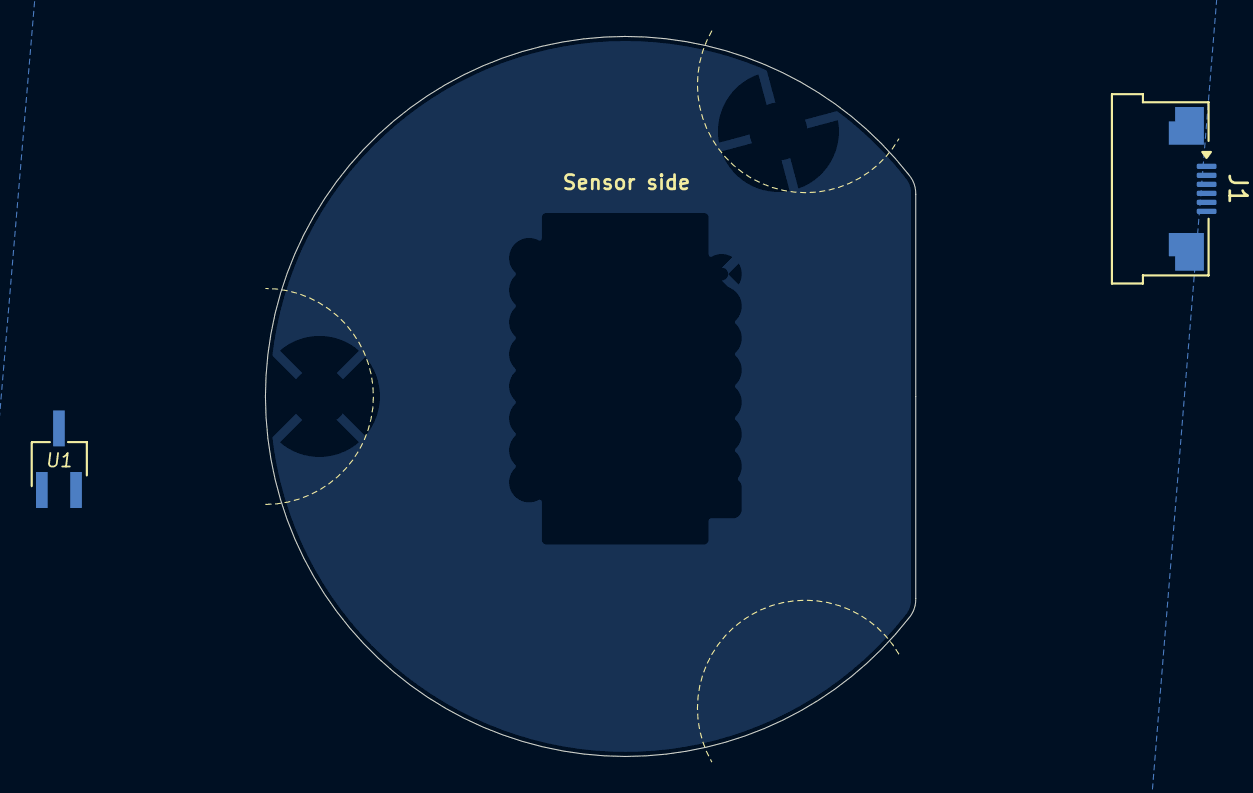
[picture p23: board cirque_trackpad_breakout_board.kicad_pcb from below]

Board: 2 copper layers, 36.1 x 40.0 mm, 8 parts (2 on the bottom side), 10 nets, no tracks yet.

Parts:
C7: 2.2uF; D_1206_3216Metric_Pad1.42x1.75mm_HandSolder
C8: 10uF; D_1206_3216Metric_Pad1.42x1.75mm_HandSolder
J1, J2: Conn_01x06; Amphenol_F32Q-1A7x1-11006_1x06-1MP_P0.5mm_Horizontal
J3: Conn_01x12; Hirose_FH12-12S-0.5SH_1x12-1MP_P0.50mm_Vertical_custom
R6, R7: 4.7k; R_1206_3216Metric_Pad1.30x1.75mm_HandSolder
U1: XC6206P332MR; TSOT-23_HandSoldering

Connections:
3V3: C7.1, J1.6, U1.3 (VI)
GND: J1.1, J2.4, J3.2
LDO_3v3: C8.1, J2.6, J3.1, R6.2, R7.2, U1.2 (VO)
MISO: J1.3, J3.11
MOSI: J1.2, J3.8
NCS: J1.5, J3.10
SCL: J2.3, J3.4, R6.1
SCLK: J1.4, J3.12
SDA: J2.5, J3.3, R7.1
_GND: C7.2, C8.2, U1.1 (GND)

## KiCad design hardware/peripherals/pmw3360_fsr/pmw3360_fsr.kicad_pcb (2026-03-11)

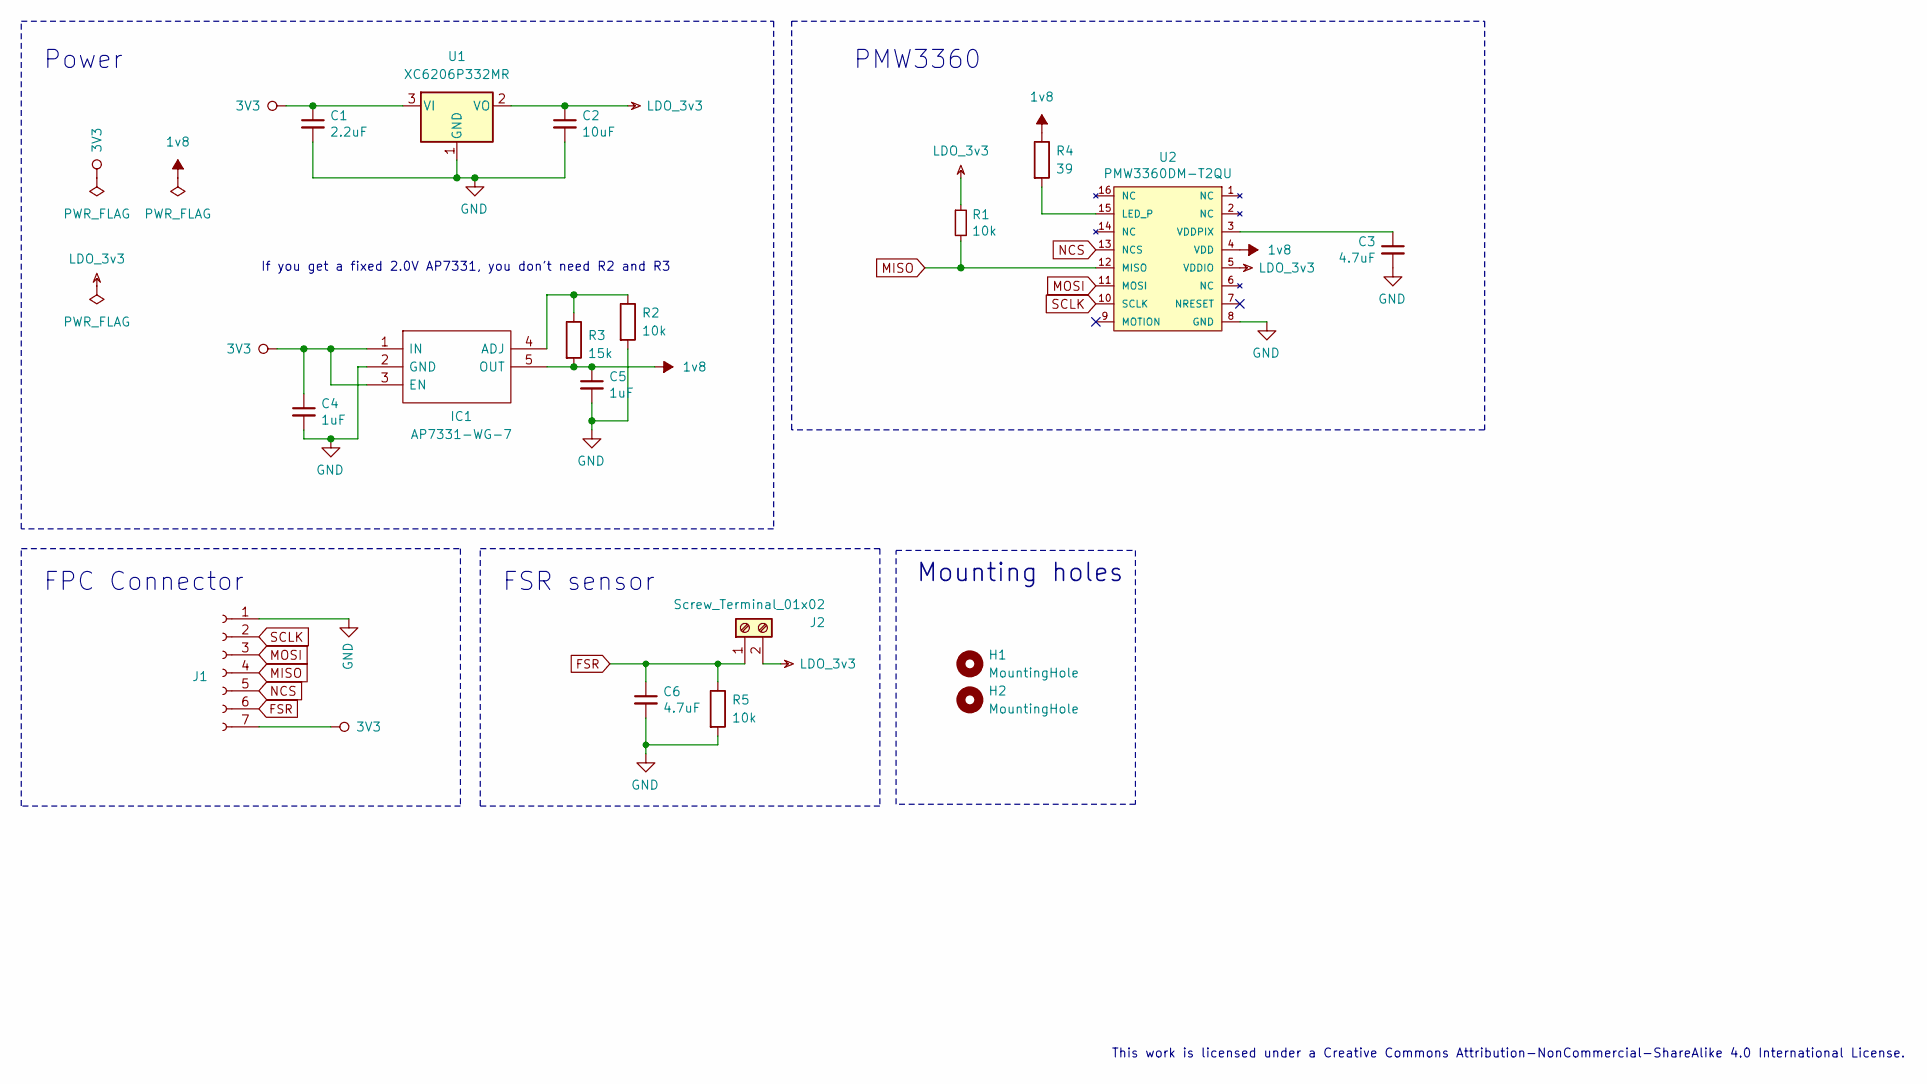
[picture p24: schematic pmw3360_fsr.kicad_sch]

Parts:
C1: 2.2uF; D_1206_3216Metric_Pad1.42x1.75mm_HandSolder; LCSC C1858
C2: 10uF; D_1206_3216Metric_Pad1.42x1.75mm_HandSolder; LCSC C152957
C3: 4.7uF; D_1206_3216Metric_Pad1.42x1.75mm_HandSolder; LCSC C29823
C4, C5: 1uF; D_1206_3216Metric_Pad1.42x1.75mm_HandSolder; LCSC C1926
C6: 4.7uF; D_1206_3216Metric_Pad1.42x1.75mm_HandSolder; LCSC C1858
H1, H2: MountingHole; MountingHole_3.2mm_M3
IC1: AP7331-WG-7; AP7331; Manufacturer_Part_Number AP7331-WG-7; Mouser Part Number 621-AP7331-WG-7
J1: Conn_01x07_Female; Conn_1x07-1MP_P0.5mm_Horizontal_Flip
J2: Screw_Terminal_01x02; TerminalBlock_Phoenix_MPT-0,5-2-2.54_1x02_P2.54mm_Horizontal
R1, R2, R5: 10k; D_1206_3216Metric_Pad1.42x1.75mm_HandSolder; LCSC C328409
R3: 15k; D_1206_3216Metric_Pad1.42x1.75mm_HandSolder; LCSC C351534
R4: 39; D_1206_3216Metric_Pad1.42x1.75mm_HandSolder; LCSC C153384
U1: XC6206P332MR; TSOT-23_HandSoldering; LCSC C347376
U2: PMW3360DM-T2QU; PMW3360DM_DIP-16_W10.16mm

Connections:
1v8: C5.1, IC1.5 (OUT), R3.2, R4.1, U2.4 (VDD)
3V3: C1.1, C4.1, IC1.1 (IN), IC1.3 (EN), J1.7, U1.3 (VI)
FSR: C6.1, J1.6, J2.1, R5.1
GND: C1.2, C2.2, C3.2, C4.2, C5.2, C6.2, IC1.2 (GND), J1.1, R2.2, R5.2, U1.1 (GND), U2.8 (GND)
LDO_3v3: C2.1, J2.2, R1.1, U1.2 (VO), U2.5 (VDDIO)
MISO: J1.4, R1.2, U2.12 (MISO)
MOSI: J1.3, U2.11 (MOSI)
NCS: J1.5, U2.13 (NCS)
unnamed: IC1.4 (ADJ), R2.1, R3.1
unnamed: R4.2, U2.15 (LED_P)
unnamed: C3.1, U2.3 (VDDPIX)
SCLK: J1.2, U2.10 (SCLK)

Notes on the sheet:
This work is licensed under a Creative Commons Attribution-NonCommercial-ShareAlike 4.0 International License.
Mounting holes
FSR sensor
If you get a fixed 2.0V AP7331, you don't need R2 and R3
Power
PMW3360
FPC Connector

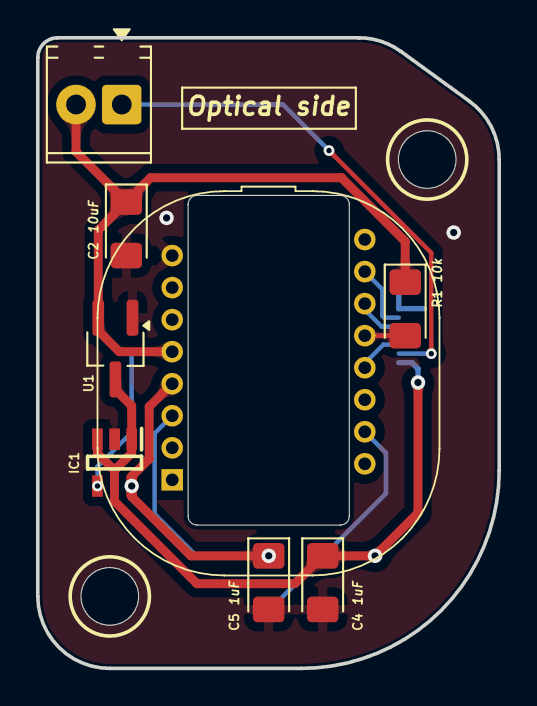
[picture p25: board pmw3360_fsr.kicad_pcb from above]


Board: 2 copper layers, 25.6 x 35.0 mm, 18 parts (9 on the bottom side), 12 nets.

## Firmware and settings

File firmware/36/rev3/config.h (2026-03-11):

/*
Copyright 2023 Jz_Wong <@wj-zhe>

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
You should have received a copy of the GNU General Public License
along with this program.  If not, see <http://www.gnu.org/licenses/>.
*/

#pragma once

/* Pointing Device */
#ifdef POINTING_DEVICE_ENABLE
#   define SPLIT_POINTING_ENABLE
#   define POINTING_DEVICE_RIGHT
#   define SPI_SCK_PIN GP2
#   define SPI_MOSI_PIN GP3
#   define SPI_MISO_PIN GP4
#   define PMW33XX_CS_PIN GP1
#endif

// FSR Sensor
#define FSR_PIN GP26

/* Encoder config */
#ifdef ENCODER_ENABLE
#   define ENCODERS_PAD_A { GP4 }
#   define ENCODERS_PAD_B { GP3 }
#   define ENCODER_RESOLUTIONS { 4 }

// #   define ENCODERS_PAD_A_RIGHT { }
// #   define ENCODERS_PAD_B_RIGHT { }
// #   define ENCODER_RESOLUTIONS_RIGHT { }

/* For 4x encoders you also can assign default position if encoder skips pulses
   when it changes direction. For example, if your encoder send high level on
   both pins by default, define this: */
// #   define ENCODER_DEFAULT_POS 0x3

#endif

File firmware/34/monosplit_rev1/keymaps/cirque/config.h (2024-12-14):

/* Copyright 2024 @wj-zhe */

#pragma once

/* Cirque trackpad config */
#ifdef POINTING_DEVICE_ENABLE
//
#   define CIRQUE_PINNACLE_DIAMETER_MM 23
#   define POINTING_DEVICE_ROTATION_180
#   define CIRQUE_PINNACLE_ATTENUATION EXTREG__TRACK_ADCCONFIG__ADC_ATTENUATE_2X
//
#   define POINTING_DEVICE_AUTO_MOUSE_ENABLE
#   define AUTO_MOUSE_TIME 150
#   define AUTO_MOUSE_DELAY 100
//
// #   define CIRQUE_PINNACLE_TAP_ENABLE
// #   define CIRQUE_PINNACLE_POSITION_MODE CIRQUE_PINNACLE_RELATIVE_MODE
// #   define CIRQUE_PINNACLE_SECONDARY_TAP_ENABLE
//
#   define POINTING_DEVICE_GESTURES_SCROLL_ENABLE
// #   define POINTING_DEVICE_GESTURES_CUSTOM_SCROLL_ENABLE
//
#   ifdef CONSOLE_ENABLE
#       define POINTING_DEVICE_DEBUG
#   endif
#endif

/* OLED config */
#ifdef OLED_ENABLE
// #   define OLED_BRIGHTNESS 128
#   define OLED_TIMEOUT 10000
#endif

/* RGB underglow options */
#ifdef RGBLIGHT_ENABLE
#   define RGBLIGHT_SLEEP
#   define RGBLIGHT_LAYERS_OVERRIDE_RGB_OFF
#endif


/* tap-hold option */
// #define TAPPING_TERM 175
#define TAPPING_TERM_PER_KEY
#define PERMISSIVE_HOLD_PER_KEY
// #define HOLD_ON_OTHER_KEY_PRESS_PER_KEY

// one-shot key/layer
#define ONESHOT_TIMEOUT 1000

// Firmware squeezing
#define LAYER_STATE_8BIT
#undef LOCKING_SUPPORT_ENABLE
#undef LOCKING_RESYNC_ENABLE
#define NO_MUSIC_MODE

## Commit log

2023-07-02 Major changes.
    [AWKB-C-0-bottom-1mm-Edge_Cuts.dxf, AWKB-C-0-bottom-1mm.kicad_pcb, AWKB-C-1-under PCB-2mm-Edge_Cuts.dxf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]
2024-02-12 Re-organized rev1 hardware files.
    [AWKB-C-0-bottom-1mm-Edge_Cuts.dxf, AWKB-C-0-bottom-1mm.kicad_pcb, AWKB-C-1-under PCB-2mm-Edge_Cuts.dxf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]
2024-02-12 Added rev2 hardware files.
    [awkb_v2_mx-B_Cu.gbl, awkb_v2_mx-B_Mask.gbs, awkb_v2_mx-B_Paste.gbp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]
2024-08-05 Grouped rev1/2 into '/split' directory
    [AWKB-C-0-bottom-1mm-Edge_Cuts.dxf, AWKB-C-0-bottom-1mm.kicad_pcb, AWKB-C-1-under PCB-2mm-Edge_Cuts.dxf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]
2024-08-05 Pre-alpha stage: Making monosplit.
    [awkb_monosplit.kicad_pcb, awkb_monosplit.kicad_sch, awkb_monosplit_switch_plate-Edge_Cuts.dxf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]
2024-08-26 Non-essential change in firmware; Modified monosplit hardward
    [awkb_monosplit.kicad_pcb, awkb_monosplit.kicad_sch]
2024-09-02 Re-organized hardware directory.. again
    [AWKB-C-0-bottom-1mm-Edge_Cuts.dxf, AWKB-C-0-bottom-1mm.kicad_pcb, AWKB-C-1-under PCB-2mm-Edge_Cuts.dxf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]
2024-09-12 Renamed files in 36 split and 34 split variants
    [34_split.kicad_pcb, 34_split.kicad_sch, 36_split.kicad_pcb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]
2024-09-12 First production (with case) commit
    [34_monosplit-B_Cu.gbr, 34_monosplit-B_Mask.gbr, 34_monosplit-B_Silkscreen.gbr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]
2024-09-22 Minor changes on case design
    [bottom_cover-Edge_Cuts.dxf, bottom_cover.kicad_pcb, cirque_plate-Edge_Cuts.dxf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]
2024-10-03 Added file wrongfully not included in previous commit
    [config.h, keymap.c]
2024-10-07 Currently settled to this firmware revision with some cirque trackpad control in a separate file. Consider auto-mouse-layer replaced with custom code in next revision.
    [config.h, keymap.c]
2024-10-19 Updated cirque trackpad contour line and alignment notches
    [34_monosplit.kicad_pcb]
2024-10-25 Addes manual OS switch; updated auto_mouse control more granual; keymap updates
2024-10-30 Made case for 23mm and 35mm cirque trackpad compatetive variants, accordingly
    [all-in-one.dxf, all-in-one.kicad_pcb, all-plates-in-one.dxf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]
2025-05-30 Splited 34 monosplit into two projects of 34 and 36 keys, respectively
    [34_monosplit-B_Cu.gbr, 34_monosplit-B_Mask.gbr, 34_monosplit-B_Silkscreen.gbr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]
2025-10-17 Removed mouse button keys on several layers
2026-03-11 First upload of v3
    Production ready main and peripheral hardware and firmware
    [34_monosplit-B_Cu.gbr, 34_monosplit-B_Mask.gbr, 34_monosplit-B_Silkscreen.gbr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]
2026-03-14 Reorganized directory completely
    [34_monosplit-B_Cu.gbr, 34_monosplit-B_Mask.gbr, 34_monosplit-B_Silkscreen.gbr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]

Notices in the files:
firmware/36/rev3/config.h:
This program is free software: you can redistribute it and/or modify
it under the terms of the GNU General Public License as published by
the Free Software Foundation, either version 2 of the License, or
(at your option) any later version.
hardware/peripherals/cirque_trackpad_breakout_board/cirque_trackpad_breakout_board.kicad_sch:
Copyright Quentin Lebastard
